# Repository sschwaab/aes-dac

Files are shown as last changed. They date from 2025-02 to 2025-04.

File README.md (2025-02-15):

# aes-dac
If you've ever found yourself running out of analog outputs on your digital mixer, you know the frustration. Maybe you have an extra stereo AES output—like we do—but no compatible gear to take it as an input.

That’s where this little device comes in. It takes the AES output of your console and converts it into a clean, balanced, line-level XLR signal (+4 dBu).

Sure, there are commercial solutions out there. But they often target high-end studio applications, making them unnecessarily expensive—sometimes costing as much as your entire mixer! We believe that great sound shouldn't come with an outrageous price tag.

Powered by a standard 9V power supply—just like your favorite guitar effects pedals—this device is easy to integrate into your setup. No frills, no overkill—just a simple and affordable solution that gets the job done.

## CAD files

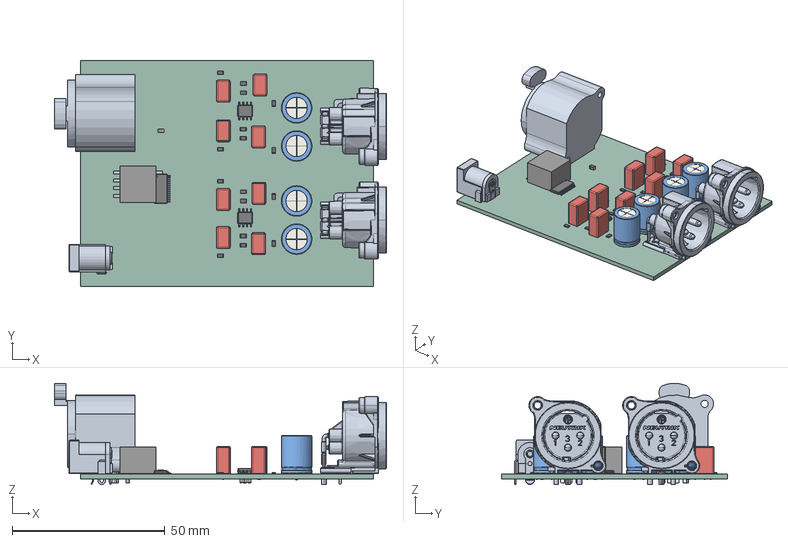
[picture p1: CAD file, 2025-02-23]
hw/AES-DAC/output/step/AES-DAC_PCB.step
108.8 x 74.0 x 33.2 mm
C_Radial_D100mm_H125mm_P500mm x 4
R_0805_2012Metric x 16
NC3MAH x 2
D-NC3FAH1
C_Rect_L72mm_W45mm_P500mm_FKS2_FKP2_MKS2_MKP2 x 8
C_0805_2012Metric x 7
SOIC_8_39x49mm_P127mm x 2
TSSOP_28_44x97mm_P065mm
ASSEMBLY
DCJ200-10-A-K1-K
_autosave-AES-DAC_PCB

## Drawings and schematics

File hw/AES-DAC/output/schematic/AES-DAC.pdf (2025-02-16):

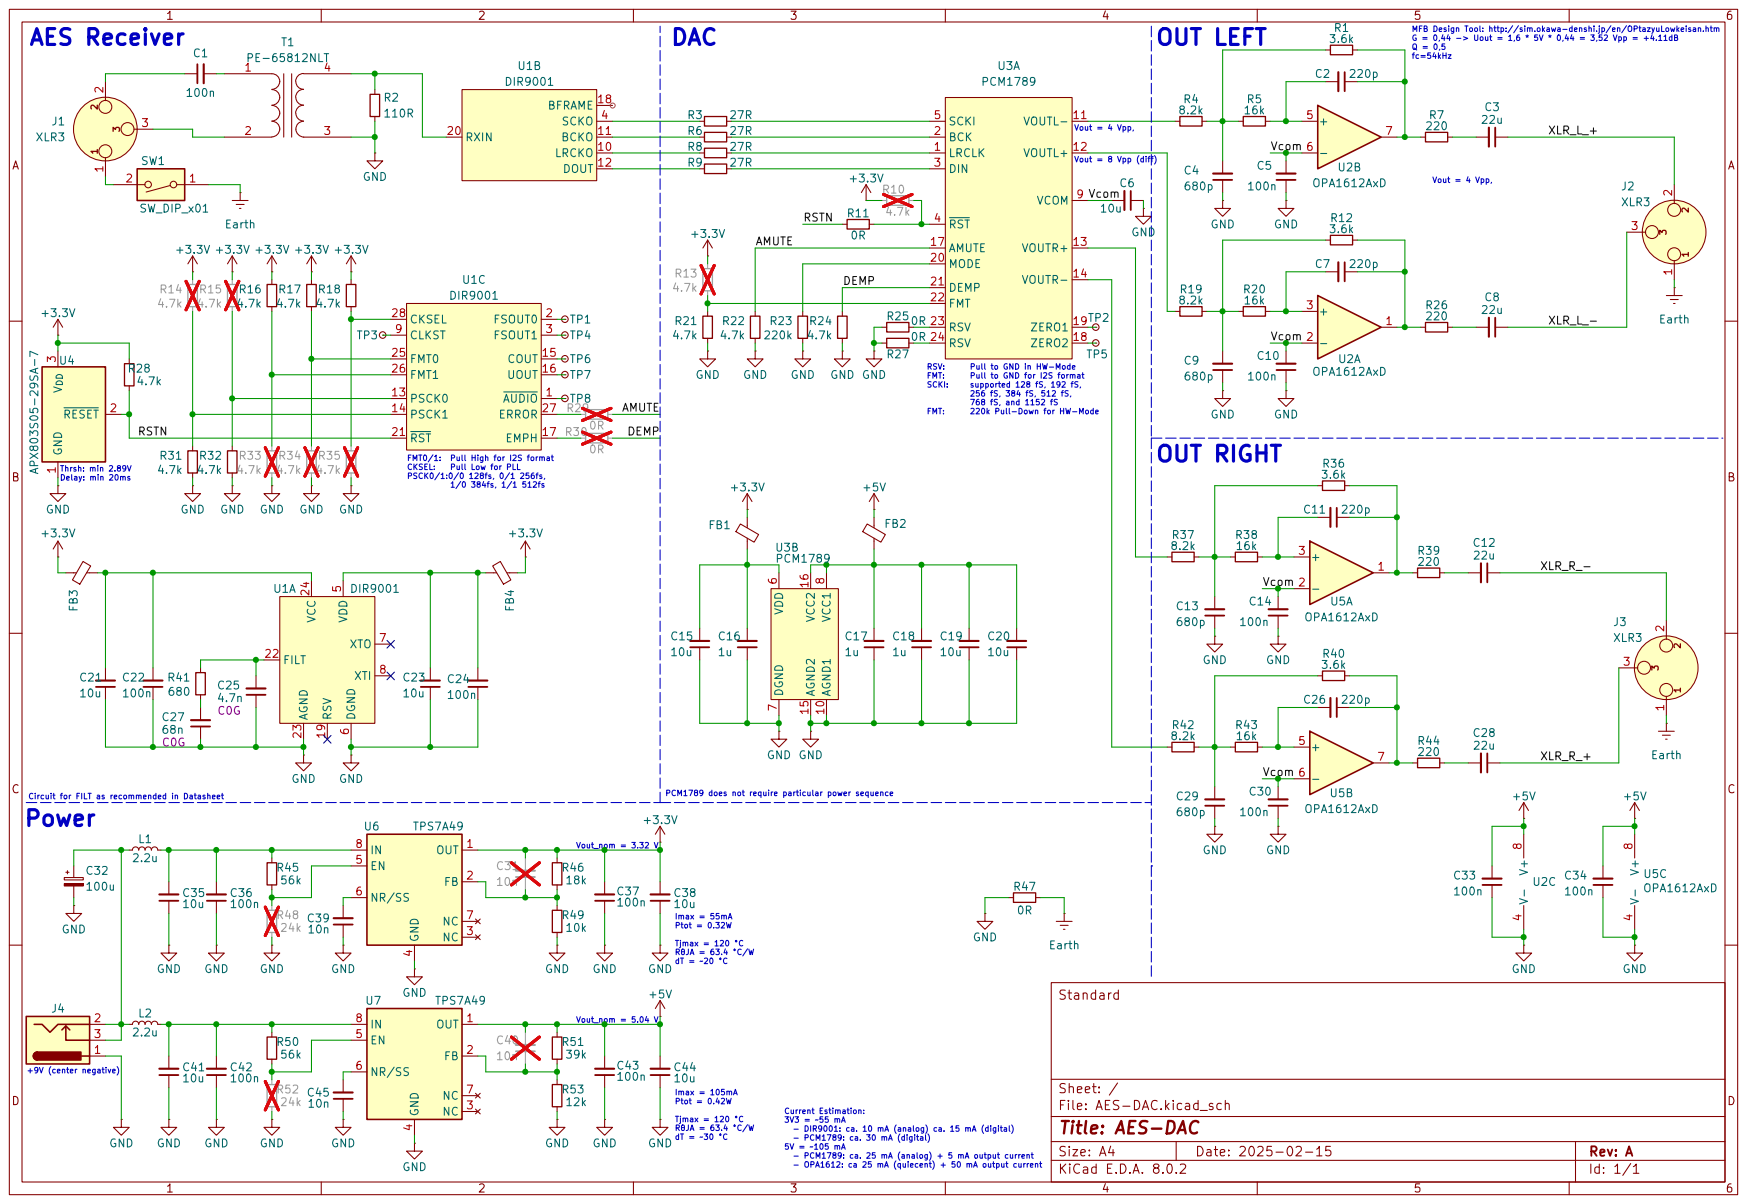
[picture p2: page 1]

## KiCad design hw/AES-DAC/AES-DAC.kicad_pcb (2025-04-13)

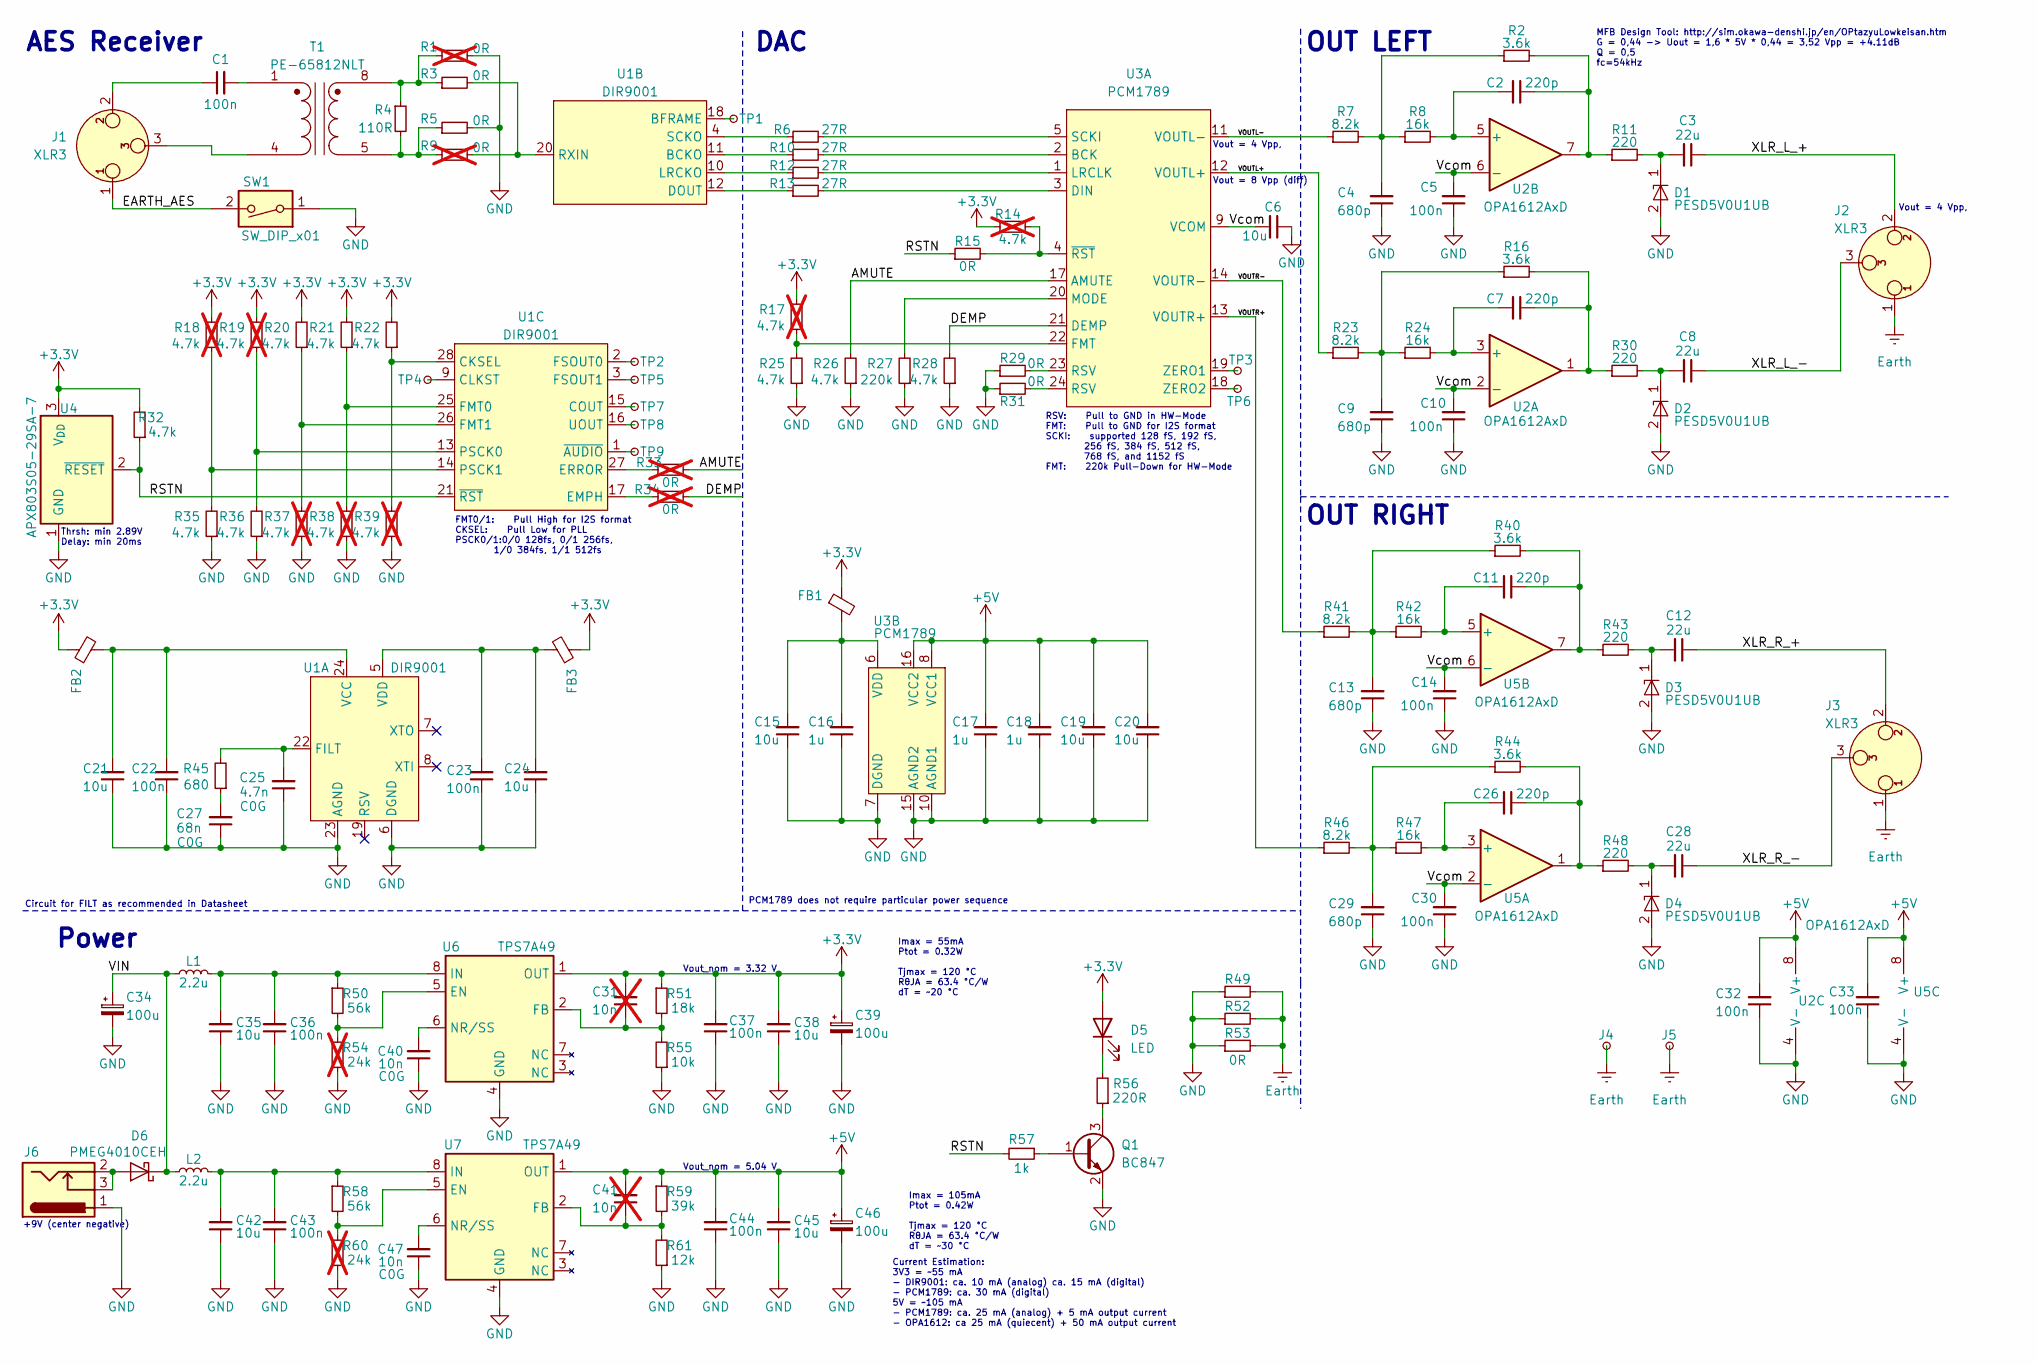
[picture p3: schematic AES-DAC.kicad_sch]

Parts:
C1, C5, C10, C14, C22, C23, C30, C32, C33, C36, C37, C43, C44: 100n; C_0805_2012Metric_Pad1.18x1.45mm_HandSolder
C2, C7, C11, C26: 220p; C_Rect_L7.2mm_W4.5mm_P5.00mm_FKS2_FKP2_MKS2_MKP2
C3, C8, C12, C28: 22u; C_Radial_D10.0mm_H12.5mm_P5.00mm
C4, C9, C13, C29: 680p; C_Rect_L7.2mm_W4.5mm_P5.00mm_FKS2_FKP2_MKS2_MKP2
C6, C15, C19, C20, C21, C24, C35, C38, C42, C45: 10u; C_0805_2012Metric_Pad1.18x1.45mm_HandSolder
C16, C17, C18: 1u; C_0805_2012Metric_Pad1.18x1.45mm_HandSolder
C25: 4.7n; C_0805_2012Metric_Pad1.18x1.45mm_HandSolder; LCSC Part C77063
C27: 68n; C_0805_2012Metric_Pad1.18x1.45mm_HandSolder; LCSC Part C77084
C31, C41: 10n; C_0805_2012Metric_Pad1.18x1.45mm_HandSolder; LCSC Part C97905; not fitted
C34, C39, C46: 100u; CP_Elec_6.3x7.7; LCSC Part C134220
C40, C47: 10n; C_0805_2012Metric_Pad1.18x1.45mm_HandSolder; LCSC Part C97905
D1, D2, D3, D4: PESD5V0U1UB; D_SOD-523; LCSC Part C2830317, C139613
D5: LED; LED_D3.0mm_Horizontal_O3.81mm_Z6.0mm
D6: PMEG4010CEH; D_SOD-123F
FB1: R_0805_2012Metric_Pad1.20x1.40mm_HandSolder
FB2, FB3: FerriteBead_Small; R_0805_2012Metric_Pad1.20x1.40mm_HandSolder
J1: XLR3; Jack_XLR_Neutrik_NC3FAH1-0_Horizontal
J2, J3: XLR3; Jack_XLR_Neutrik_NC3MAH-0_Horizontal
J4, J5: TestPoint_Small; TestPoint_THTPad_D2.0mm_Drill1.0mm
J6: DCJ200-10-A-K1-K; BarrelJack_GCT_DCJ200-10-A_Horizontal
L1, L2: 2.2u; L_1206_3216Metric
Q1: BC847; SOT-23
R1, R9, R33, R34: 0R; R_0603_1608Metric_Pad0.98x0.95mm_HandSolder; not fitted
R2, R16, R40, R44: 3.6k; R_0805_2012Metric_Pad1.20x1.40mm_HandSolder
R3, R5, R15, R29, R31: 0R; R_0603_1608Metric_Pad0.98x0.95mm_HandSolder
R4: 110R; C_0805_2012Metric_Pad1.18x1.45mm_HandSolder
R6, R10, R12, R13: 27R; R_0603_1608Metric_Pad0.98x0.95mm_HandSolder
R7, R23, R41, R46: 8.2k; R_0805_2012Metric_Pad1.20x1.40mm_HandSolder
R8, R24, R42, R47: 16k; R_0805_2012Metric_Pad1.20x1.40mm_HandSolder
R11, R30, R43, R48: 220; R_0805_2012Metric_Pad1.20x1.40mm_HandSolder
R14, R17, R18, R19, R37, R38, R39: 4.7k; R_0603_1608Metric_Pad0.98x0.95mm_HandSolder; not fitted
R20, R21, R22, R25, R26, R28, R32, R35, R36: 4.7k; R_0603_1608Metric_Pad0.98x0.95mm_HandSolder
R27: 220k; R_0603_1608Metric_Pad0.98x0.95mm_HandSolder
R45: 680; R_0805_2012Metric_Pad1.20x1.40mm_HandSolder
R49, R52, R53: 0R; R_0805_2012Metric_Pad1.20x1.40mm_HandSolder
R50, R58: 56k; R_0805_2012Metric_Pad1.20x1.40mm_HandSolder
R51: 18k; R_0805_2012Metric_Pad1.20x1.40mm_HandSolder
R54, R60: 24k; R_0805_2012Metric_Pad1.20x1.40mm_HandSolder; not fitted
R55: 10k; R_0805_2012Metric_Pad1.20x1.40mm_HandSolder
R56: 220R; R_0805_2012Metric_Pad1.20x1.40mm_HandSolder
R57: 1k; R_0603_1608Metric_Pad0.98x0.95mm_HandSolder
R59: 39k; R_0805_2012Metric_Pad1.20x1.40mm_HandSolder
R61: 12k; R_0805_2012Metric_Pad1.20x1.40mm_HandSolder
SW1: SW_DIP_x01; SW_DIP_SPSTx01_Slide_6.7x4.1mm_W6.73mm_P2.54mm_LowProfile_J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; LCSC Part C19272173
T1: PE-65812NLT
TP1, TP2, TP3, TP4, TP5, TP6, TP7, TP8, TP9: TestPoint_Small; TestPoint_Pad_D1.0mm
U1: DIR9001; TSSOP-28_4.4x9.7mm_P0.65mm
U2, U5: OPA1612AxD; SOIC-8_3.9x4.9mm_P1.27mm; LCSC Part C94590
U3: PCM1789; TSSOP-24_4.4x7.8mm_P0.65mm
U4: APX803S05-29SA-7; SOT-23; LCSC Part C2067629
U6, U7: TPS7A49; HVSSOP-8-1EP_3x3mm_P0.65mm_EP1.57x1.89mm_ThermalVias; LCSC Part C16430

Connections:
+3.3V: C31.2, C37.2, C38.2, C39.1, D5.2 (A), FB1.1, FB2.1, FB3.1, R14.1, R17.2, R18.2, R19.2, R20.2, R21.2, R22.2, R32.2, R51.1, U4.3 (V_{DD}), U6.1 (OUT)
+5V: C17.2, C18.2, C19.2, C20.2, C32.2, C33.2, C41.2, C44.2, C45.2, C46.1, R59.1, U2.8 (V+), U3.8 (VCC1), U3.16 (VCC2), U5.8 (V+), U7.1 (OUT)
/AMUTE: R26.2, R33.2, U3.17 (AMUTE)
/DEMP: R28.2, R34.2, U3.21 (DEMP)
/EARTH_AES: J1.1, SW1.2
/RSTN: R15.1, R32.1, R57.2, U1.21 (~RST), U4.2 (~RESET)
/VIN: C34.1, D6.1 (K), L1.1, L2.1
/VOUTL+: R23.1, U3.12 (VOUTL+)
/VOUTL-: R7.1, U3.11 (VOUTL-)
/VOUTR+: R46.1, U3.13 (VOUTR+)
/VOUTR-: R41.1, U3.14 (VOUTR-)
/Vcom: C5.2, C6.2, C10.2, C14.2, C30.2, U2.2 (-), U2.6 (-), U3.9 (VCOM), U5.2 (-), U5.6 (-)
/XLR_L_+: C3.1, J2.2
/XLR_L_-: C8.1, J2.3
/XLR_R_+: C12.1, J3.2
/XLR_R_-: C28.1, J3.3
Earth: J2.1, J3.1, J4.1, J5.1, R49.2, R52.2, R53.2
GND: C4.1, C5.1, C6.1, C9.1, C10.1, C13.1, C14.1, C15.1, C16.1, C17.1, C18.1, C19.1, C20.1, C21.1, C22.1, C23.1, C24.1, C25.1, C27.1, C29.1, C30.1, C32.1, C33.1, C34.2, C35.1, C36.1, C37.1, C38.1, C39.2, C40.1, C42.1, C43.1, C44.1, C45.1, C46.2, C47.1, D1.2, D2.2, D3.2, D4.2, J6.1, Q1.2 (E), R1.2, R5.2, R25.1, R26.1, R27.1, R28.1, R29.1, R31.1, R35.1, R36.1, R37.1, R38.1, R39.1, R49.1, R52.1, R53.1, R54.2, R55.1, R60.2, R61.1, SW1.1, U1.6 (DGND), U1.23 (AGND), U2.4 (V-), U3.7 (DGND), U3.10 (AGND1), U3.15 (AGND2), U4.1 (GND), U5.4 (V-), U6.4 (GND), U6.9 (GND), U7.4 (GND), U7.9 (GND)
unnamed: C1.1, J1.2
unnamed: C1.2, T1.1
unnamed: C2.1, R2.2, R11.1, U2.7
unnamed: C3.2, D1.1, R11.2
unnamed: C4.2, R2.1, R7.2, R8.1
unnamed: C7.1, R16.2, R30.1, U2.1
unnamed: C8.2, D2.1, R30.2
unnamed: C9.2, R16.1, R23.2, R24.1
unnamed: C11.1, R40.2, R43.1, U5.7
unnamed: C12.2, D3.1, R43.2
unnamed: C13.2, R40.1, R41.2, R42.1
unnamed: C26.1, R44.2, R48.1, U5.1
unnamed: C27.2, R45.1
unnamed: C28.2, D4.1, R48.2
unnamed: C29.2, R44.1, R46.2, R47.1
unnamed: D5.1 (K), R56.2
unnamed: D6.2 (A), J6.2, J6.3
unnamed: J1.3, T1.4
unnamed: Q1.1 (B), R57.1
unnamed: Q1.3 (C), R56.1
unnamed: R1.1, R3.1, R4.1, T1.8
unnamed: R4.2, R5.1, R9.1, T1.5
unnamed: R29.2, U3.23 (RSV)
unnamed: R31.2, U3.24 (RSV)
unnamed: C25.2, R45.2, U1.22 (FILT)
unnamed: C21.2, C22.2, FB2.2, U1.24 (VCC)
unnamed: C23.2, C24.2, FB3.2, U1.5 (VDD)
unnamed: R10.1, U1.11 (BCKO)
unnamed: TP1.1, U1.18 (BFRAME)
unnamed: R13.1, U1.12 (DOUT)
unnamed: R12.1, U1.10 (LRCKO)
unnamed: R3.2, R9.2, U1.20 (RXIN)
unnamed: R6.1, U1.4 (SCKO)
unnamed: R22.1, R39.2, U1.28 (CKSEL)
unnamed: TP4.1, U1.9 (CLKST)
unnamed: TP7.1, U1.15 (COUT)
unnamed: R34.1, U1.17 (EMPH)
unnamed: R33.1, U1.27 (ERROR)
unnamed: R21.1, R38.2, U1.25 (FMT0)
unnamed: R20.1, R37.2, U1.26 (FMT1)
unnamed: TP2.1, U1.2 (FSOUT0)
unnamed: TP5.1, U1.3 (FSOUT1)
unnamed: R19.1, R36.2, U1.13 (PSCK0)
unnamed: R18.1, R35.2, U1.14 (PSCK1)
unnamed: TP8.1, U1.16 (UOUT)
unnamed: TP9.1, U1.1 (~AUDIO)
unnamed: C7.2, R24.2, U2.3 (+)
unnamed: C2.2, R8.2, U2.5 (+)
unnamed: R10.2, U3.2 (BCK)
unnamed: R13.2, U3.3 (DIN)
unnamed: R17.1, R25.2, U3.22 (FMT)
unnamed: R12.2, U3.1 (LRCLK)
unnamed: R27.2, U3.20 (MODE)
unnamed: R6.2, U3.5 (SCKI)
unnamed: TP3.1, U3.19 (ZERO1)
unnamed: TP6.1, U3.18 (ZERO2)
unnamed: R14.2, R15.2, U3.4 (~RST)
unnamed: C15.2, C16.2, FB1.2, U3.6 (VDD)
unnamed: C26.2, R47.2, U5.3 (+)
unnamed: C11.2, R42.2, U5.5 (+)
unnamed: R50.2, R54.1, U6.5 (EN)
unnamed: C31.1, R51.2, R55.2, U6.2 (FB)
unnamed: C35.2, C36.2, L1.2, R50.1, U6.8 (IN)
unnamed: C40.2, U6.6 (NR/SS)
unnamed: R58.2, R60.1, U7.5 (EN)
unnamed: C41.1, R59.2, R61.2, U7.2 (FB)
unnamed: C42.2, C43.2, L2.2, R58.1, U7.8 (IN)
unnamed: C47.2, U7.6 (NR/SS)

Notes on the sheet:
Current Estimation: 3V3 = ~55 mA - DIR9001: ca. 10 mA (analog) ca. 15 mA (digital) - PCM1789: ca. 30 mA (digital) 5V = ~105 mA - PCM1789: ca. 25 mA (analog) + 5 mA output current - OPA1612: ca 25 mA (quiecent) + 50 mA output current
PCM1789 does not require particular power sequence
DAC
Power
OUT LEFT
Imax = 105mA Ptot = 0.42W Tjmax = 120 °C RθJA = 63.4 °C/W dT = ~30 °C
+9V (center negative)
Vout_nom = 3.32 V
Vout = 4 Vpp,
Vout = 8 Vpp (diff)
Thrsh: min 2.89V Delay: min 20ms
OUT RIGHT
RSV: Pull to GND in HW-Mode FMT: Pull to GND for I2S format SCKI: supported 128 fS, 192 fS, 256 fS, 384 fS, 512 fS, 768 fS, and 1152 fS FMT: 220k Pull-Down for HW-Mode
AES Receiver
MFB Design Tool: http://sim.okawa-denshi.jp/en/OPtazyuLowkeisan.htm G = 0,44 -> Uout = 1,6 * 5V * 0,44 = 3,52 Vpp = +4.11dB Q = 0,5 fc=54kHz
Circuit for FILT as recommended in Datasheet
Imax = 55mA Ptot = 0.32W Tjmax = 120 °C RθJA = 63.4 °C/W dT = ~20 °C
Vout_nom = 5.04 V
FMT0/1: Pull High for I2S format CKSEL: Pull Low for PLL PSCK0/1:0/0 128fs, 0/1 256fs, 1/0 384fs, 1/1 512fs

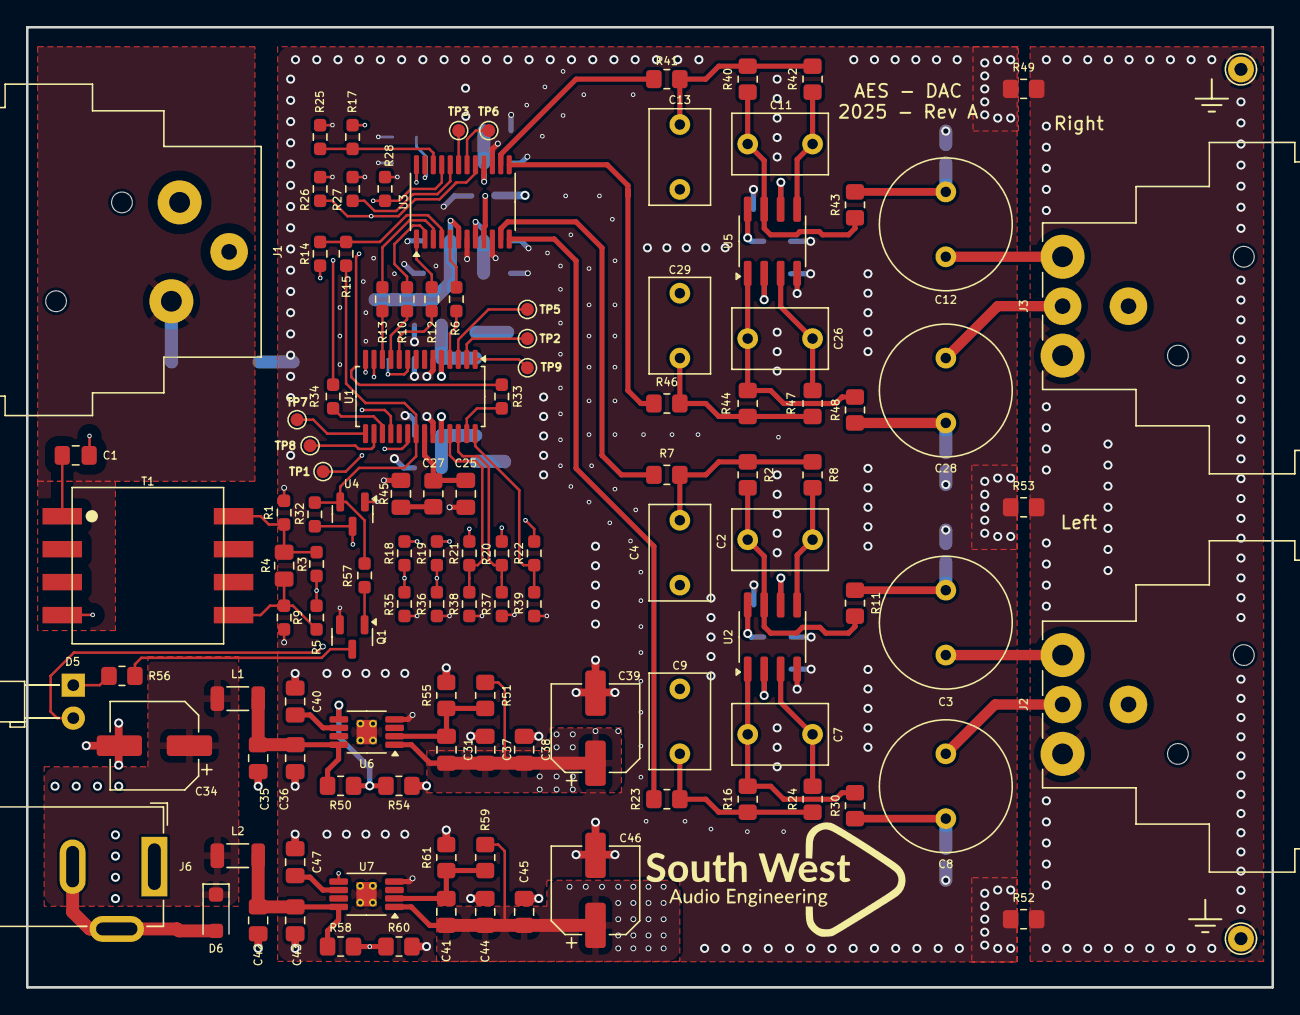
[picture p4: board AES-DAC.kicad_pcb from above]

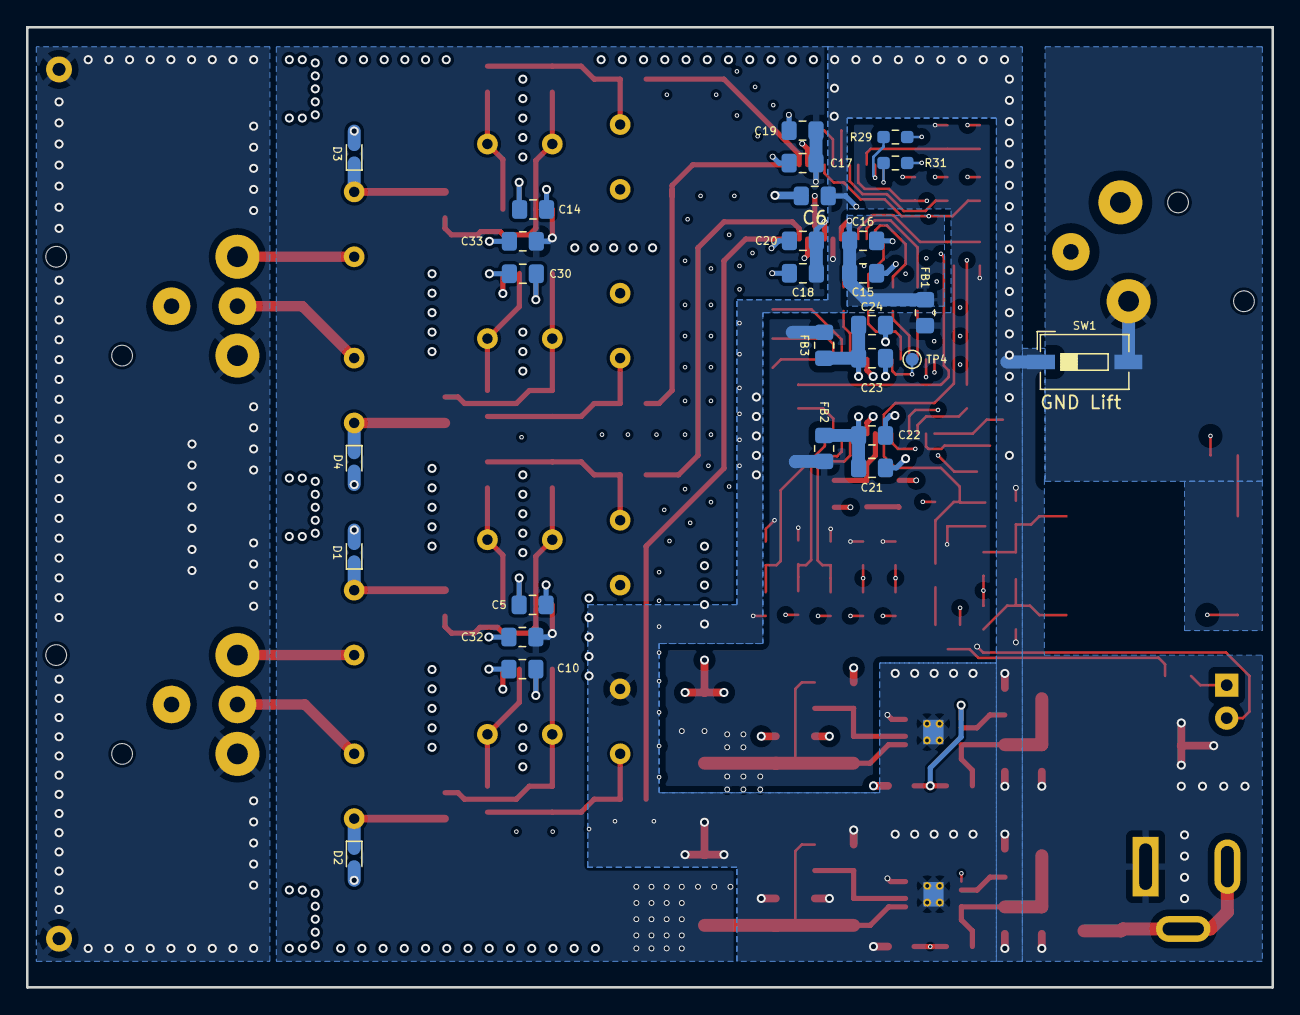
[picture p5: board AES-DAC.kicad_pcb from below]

Board: 4 copper layers, 96.0 x 74.0 mm, 144 parts (28 on the bottom side), 86 nets.

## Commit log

2025-02-15 First commit. Schematic first version done.
    [AES-DAC.kicad_pcb, AES-DAC.kicad_sch]
2025-02-16 minor corrections in schematic
    [AES-DAC.kicad_sch]
2025-02-16 wrong orientation of schematic
2025-02-16 Annotated schematic
    [AES-DAC.kicad_sch]
2025-02-23 Added: Simulation for Jitter analysis PCB File Updated: Schematic
    [AES-DAC.kicad_pcb, AES-DAC.kicad_sch, AES-DAC_PCB.step]
2025-03-07 layout update
    [AES-DAC.kicad_pcb, AES-DAC.kicad_sch]
2025-04-13 Added Gerbers and did some improvements
    [AES-DAC-B_Cu.gbr, AES-DAC-B_Mask.gbr, AES-DAC-B_Silkscreen.gbr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]
